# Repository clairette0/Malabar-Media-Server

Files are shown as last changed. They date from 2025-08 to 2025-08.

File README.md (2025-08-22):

# <div align="center">Malabar Media Server</div>

<div align="center">
  Malabar Media Server Offline Media Server
</div>

<p align="center"><b>A portable, offline media server powered by the ESP32-S3 in a thumbdrive form factor.</b><br>
Stream movies, music, books, and shows anywhere — no internet required.</p>

<p align="center">
  
  
  
</p>

---

##  Polish Update Disclaimer

This is a major update focused on **polish, stability, and usability improvements**.  
It includes:

- Full cleanup of reported bugs  
- Improved user interface  
- Rebuilt admin panel  
- New features across every section  
- All configuration options now available in the **frontend** — no need to modify firmware to change settings  
- Greatly enhanced file and media support  

---

## New Features in the Polish Update

###  Music Page

- Song downloads
- Loop songs 
- Sort songs A–Z
- Shuffle songs and playlists
- Playlist support via subfolders (flexible usage)
- Playlists loop automatically
- Expanded file type support: tested with `.mp3`, `.wav`, and `.flac` (others may work, untested)

###  Books Page

- EPUB support added (no web reader yet, but download works)
- Fixed footer CSS display issue

###  Admin Panel (Completely Rebuilt)

- Restart the device directly from the panel
- Switch to USB Mass Storage Mode with one click
- SD card usage tracking with visual indicators
- Control RGB LED color and mode
- Change or disable the admin password (for admin page access) (default is "password")
- Change Wi-Fi SSID and password
- Set device brightness (off option coming soon)
- Toggle `media.json` auto-generation on boot
- Generate `media.json` manually
- Display connected Wi-Fi info and number of connected users
- Integrated file system browser with jQueryFileTree:
  - Upload, delete, rename, download, create folder, and edit files (basic inline code editor)
  - Improved UX over the original browser, but still allows dangerous deletions, use with care.

###  Gallery Page (New)

- Displays images with basic zoom functionality
- Video playback support
- Sortable display grid

###  Files Page (New)

- Lets you store and download any file type
- Still limited to FAT32 file size limit (4 GB max)
- Useful for sharing non-media files like firmware, PDFs, etc.

###  Interface + UI Improvements

- LCD now displays “USB Mass Storage Mode” clearly — no more frozen screen confusion
- `media.json` generation displays file names in real-time on screen
- More intuitive screen feedback during long operations

###  File Type & Playback Support

- Improved video file detection and browser compatibility
- Works with almost all browser-supported video types
- Unsupported files fall back to download behavior

###  Admin Access Notes

- A new "Settings" button on the top-right of the menu screen leads to the Admin Panel
- Default admin password is `"password"`
- If locked out, inspect (F12) the overlay and delete it manually to regain access
- All settings now persist across reboots

---

## Experimental Branch Enhancements

This branch includes all current features being tested for stability before merging into `main`.

### Key Features

- Admin panel with controls for restart, USB mode, Wi-Fi, RGB, brightness, password, and media generation
- Frontend-based configuration (no firmware edits required)
- Full file system browser with upload, rename, delete, and inline editing
- Music player with playlist support, shuffle, loop, downloads, and file sorting
- Expanded audio format support (MP3, WAV, FLAC, and others)
- Books section with PDF support (and limited Epub support)
- Gallery page for browsing images and video playback
- Files page for general-purpose file sharing and downloads
- Media.json generation with live progress shown on screen
- LCD interface with USB mode status and SD card usage display
- Captive portal for easy user access
- OPDS support for eBook integration
- Basic DLNA support for media discovery on supported devices
- Custom UI built with SquareLine Studio
- Persistent settings stored across reboots
- Improved mobile-friendly web UI

Use this branch if you want the most up to date features, improved stability, and a much more polished experience. While still under active development, this is now the recommended version for most users and I will be pushing it to main after a few days of user testing. 

---

## What is Malabar Media Server

Malabar Media Server is an open-source offline media server built for travel, remote work, classrooms, camping, and more. It runs entirely on an ESP32-S3 dev board, creates a local Wi-Fi hotspot, and serves media through a browser-accessible interface. It does not require internet access and works similarly to in-flight entertainment systems. It also allows multiple users watching seperate media streams at the same time. 

This project is designed to be compact, simple, and easily modifiable. It includes optional 3D-printable hardware and a fully open source firmware and web interface.

---

## Project Inspiration
This project was inspired by my experience running a Jellyfin server at home. I love having full control over my media library, and Jellyfin gave me everything I wanted > streaming movies, shows, books, and music, all from my own hardware. Naturally, I started looking for ways to take that experience on the go.

My first thought was to build a portable server, but I quickly ran into some major hurdles:

- Power-hungry hardware — Even low-power x86 boxes needed a hefty battery setup to stay running for long trips.

- High cost — SBCs like the Raspberry Pi 4, plus power banks, USB storage, and screen interfaces added up quickly.

- Heat and reliability — Trying to cram a full stack of services into a compact case often led to thermal issues and instability when running software meant for server hardware.

That’s when I pivoted.

Instead of replicating a full home media server, I focused on delivering the core experience:

- Offline access

- Local Wi-Fi hotspot

- Simple media browsing and playback

- Support for multiple users

The ESP32-S3 offered just enough performance to handle all of that - with a fraction of the power draw and cost.
The result is Malabar Media Server: a minimalist, reliable, and low-cost media server that delivers the essential features of a home streaming setup in a smaller than pocket sized format.

Is it fancy? No.
Does it work? Absolutely.
And it’s open-source, so anyone can expand, improve, and adapt it for their own needs.

---

## Features

- Creates a local Wi-Fi hotspot with captive portal  
- Serves HTML media interface to any connected device  
- Streams content directly from a FAT32-formatted microSD card  
- Supports simultaneous connections (tested with up to 4 video streams)  
- No app or internet connection required  
- Open source firmware and UI  
- Customizable web interface / Features

---

## Hardware Requirements

**Disclaimer:**  
The following links are Amazon affiliate links. Purchasing through these links supports this project at no additional cost to you. Thank you for your support!

- **Waveshare ESP32-S3 Dev Board (1.47" LCD version)**  
  [https://amzn.to/4ktB6oT](https://amzn.to/4ktB6oT)

- **FAT32-formatted microSD card (16 GB minimum recommended, 64 GB preferred)**  
  [https://amzn.to/44tM1c4](https://amzn.to/44tM1c4)

- **SD-Card Extender** Not needed, but useful for the latest case version, lets you get to the SD card without disasembly. 
  [https://amzn.to/45IWIJz](https://amzn.to/45IWIJz)

- **USB power source** (e.g., battery bank or computer)

- **Optional:** 3D-printed enclosure (STL files included in the repository)

---

## Software Requirements

- Arduino IDE or PlatformIO (to flash firmware)
- Python 3.x (to run `media.py`)
- SquareLine Studio (optional, for screen UI editing)

All software used is free and available on Windows, macOS, and Linux.

---

## Quick Start

1. Flash the ESP32-S3 with the firmware in the `/firmware/` directory.
2. Format your SD card as **FAT32** and copy the web files from `/SD_Card_Template/`.
3. Place your media files into the appropriate folders (see structure below).
4. Run `media.py` to generate `media.json` automatically.
5. Insert the SD card and power the device.
6. Connect to the Wi-Fi network named `Malabar_Media_Server`.
7. Your browser will be redirected to the offline media interface.

---

## Folder Structure (on SD Card)

```
/Movies/
    Interstellar.mp4
    Interstellar.jpg
/Shows/
    The Office/
        S01E01 - Pilot.mp4
        S01E02 - Diversity Day.mp4
    The Office.jpg
/Books/
    The Martian.pdf
    The Martian.jpg
/Music/
    track01.mp3

index.html
appleindex.html
menu.html
movies.html
shows.html
books.html
music.html
media.py
media.json
placeholder.jpg
Logo.png
favicon.ico
```
---

## Supported Formats

- Video: `.mp4`
- Audio: `.mp3`
- Books: `.pdf`
- Images: `.jpg` (used for covers and folder images only)

Ensure all images and media files use matching names for proper display.

---

## Customization

- Wi-Fi name and password can be changed in `firmware/MalabarMediaServerProject/MalabarMediaServerProject.ino`
- Branding (logo, favicon) can be replaced in `/SD_Card_Template/`
- Sections (Movies, Music, etc.) can be removed from `menu.html`
- Web interface can be edited using any text editor
- The screen UI can be edited with SquareLine Studio (the free version is fine) 

---

## What's Included

- `/firmware/` – Arduino firmware for ESP32-S3
- `/SD_Card_Template/` – Web UI, HTML files, and `media.py`
- `/case/` – STL files for optional 3D-printed enclosure
- `/docs/` – Logos, screenshots, and design files

---

## Troubleshooting

Common issues and their solutions are detailed in the Troubleshooting section on instructibles.

Topics covered include:

- SD card read errors
- Captive portal issues on some phones
- Video playback and seeking bugs
- UI glitches or screen failure

---

## Future Plans

These are features I'd like to explore in future updates. If you'd like to contribute, feel free to fork the repo or open a pull request!

### Offline Maps with GPS Support
Inspired by [Backcountry Beacon](https://www.instructables.com/USB-Powered-Offline-Map-Server/), the goal is to serve cached map tiles and display the live GPS position from the user's phone or connected device — entirely offline.

### HTML5 Games
Similar to [Gams Offline](https://github.com/Gams-Offline/Gams), I would like to embed simple HTML5 games that work in-browser. The selection in Gams is amazing and make me think of cool math games, would be neat to have even though most require a keyboard.

### Audiobook-Friendly Mode
Improve playback for long-form audio by adding bookmarks, chapter display, and smart pause/resume. Intended for better audiobook handling in the Music section. Potentialy add an entire new audiobook section or a seperate handling system for it in books (Under read it could have a listen option).

---

## Build Guide on Instructables

Looking for a step-by-step tutorial?  
Check out the full build guide on **Instructables** for detailed instructions, photos, and tips on setting up Malabar Media Server.

👉 [Read the Instructables Guide](https://www.instructables.com/Jcorp-Nomad-Mini-WIFI-Media-Server/) 

---

## License

This project is licensed under the [Creative Commons Attribution-NonCommercial-ShareAlike 4.0 International License](https://creativecommons.org/licenses/by-nc-sa/4.0/).

You may remix, adapt, and share this project **for non-commercial use**, as long as you give credit and share under the same terms.

For commercial licensing, please contact the author.

---

## Credits

Developed by **Jackson Studner (Jcorp Tech)**.  
Inspired by open-source offline projects like Backcountry Beacon.

If you build, remix, or improve this project, please consider submitting a pull request or tagging the project.

---

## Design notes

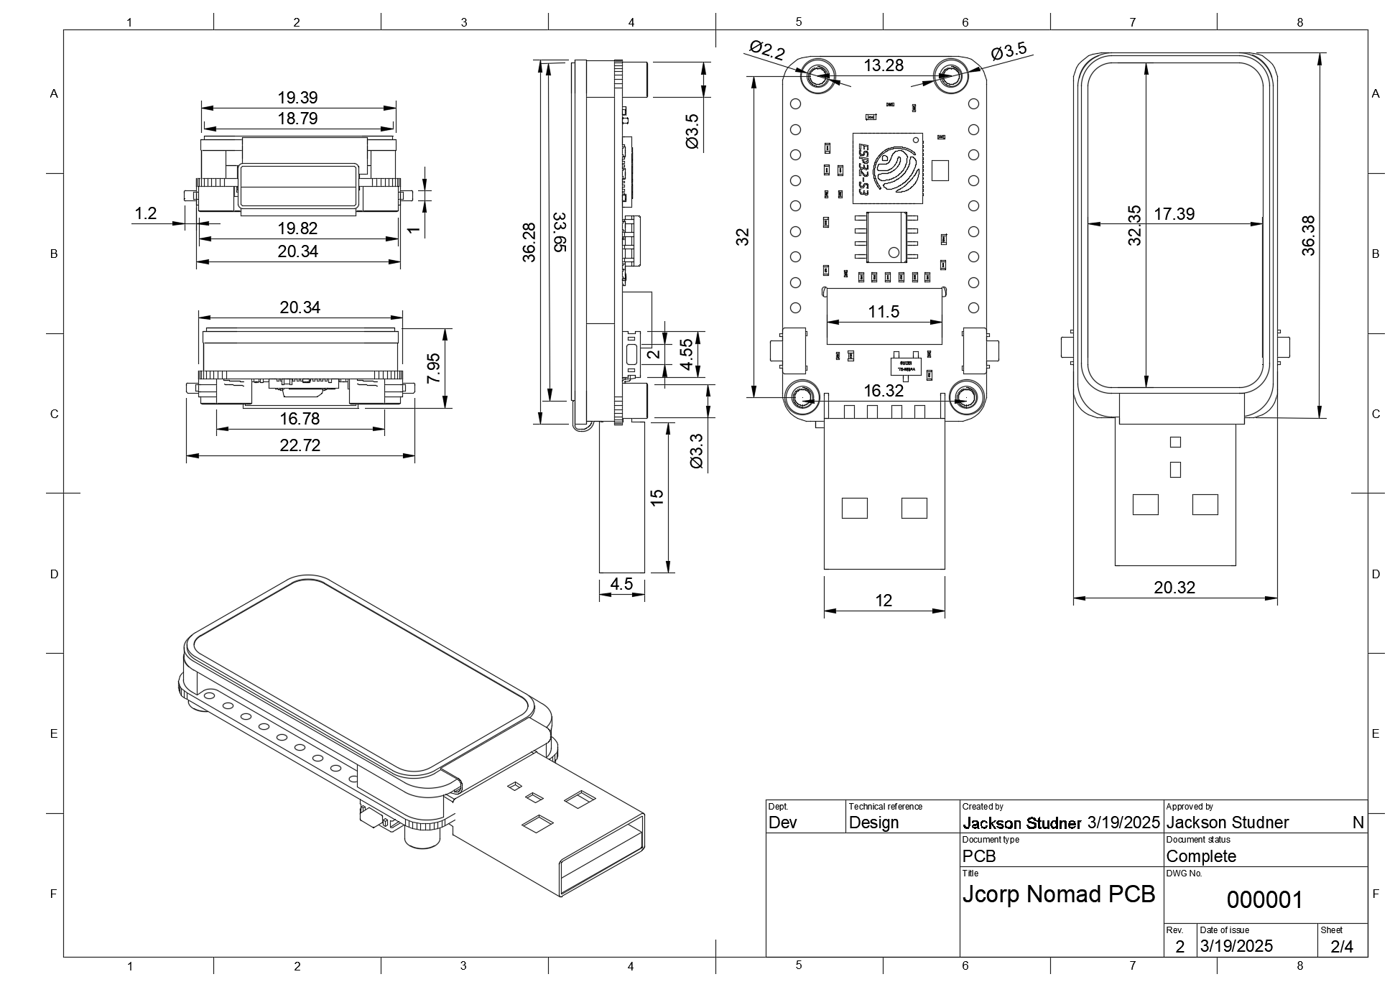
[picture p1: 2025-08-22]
docs/Malabar Technical Diagram.png

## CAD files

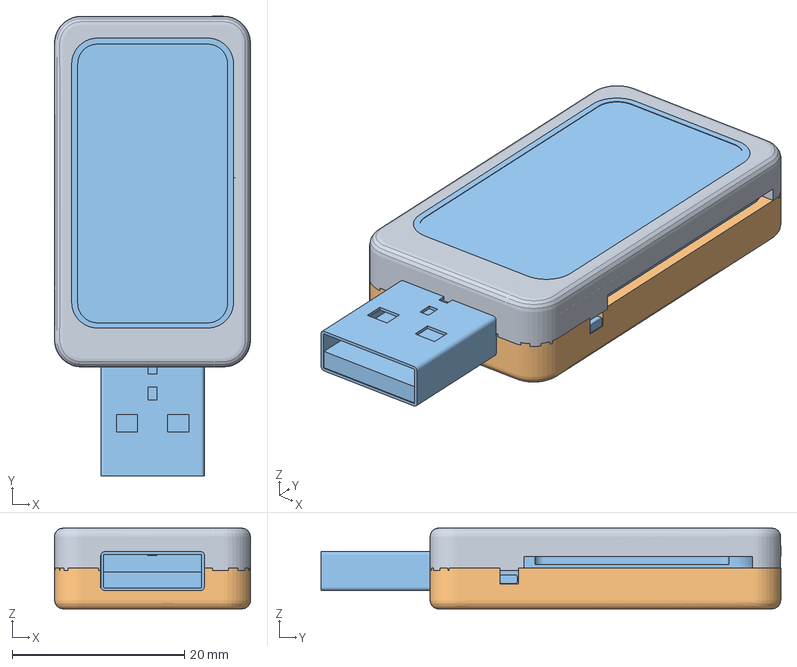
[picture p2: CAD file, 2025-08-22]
docs/MalabarFullTest.3mf
22.7 x 53.3 x 9.39 mm

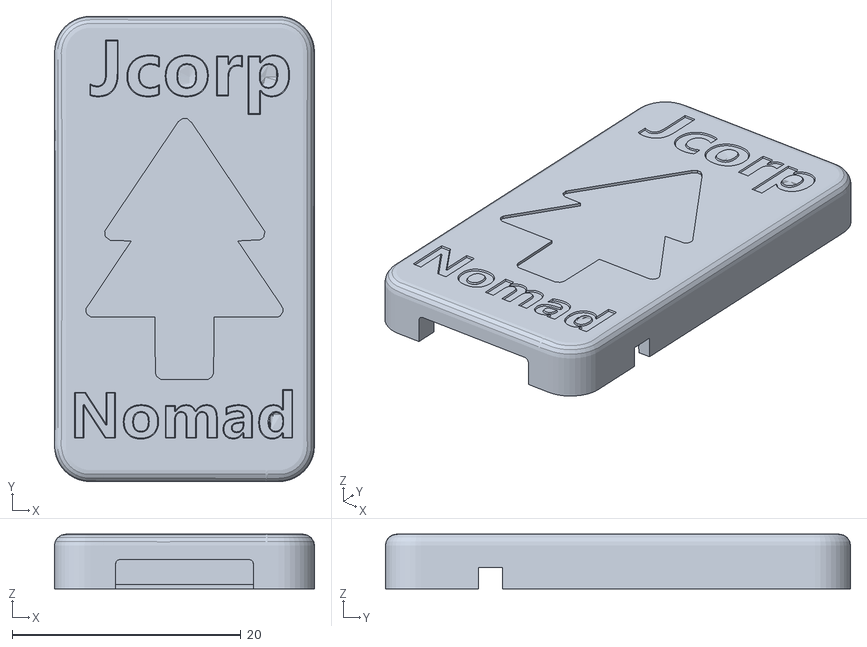
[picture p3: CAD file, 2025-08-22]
case/MalabarMediaServerBackCover.stl
22.7 x 40.7 x 4.78

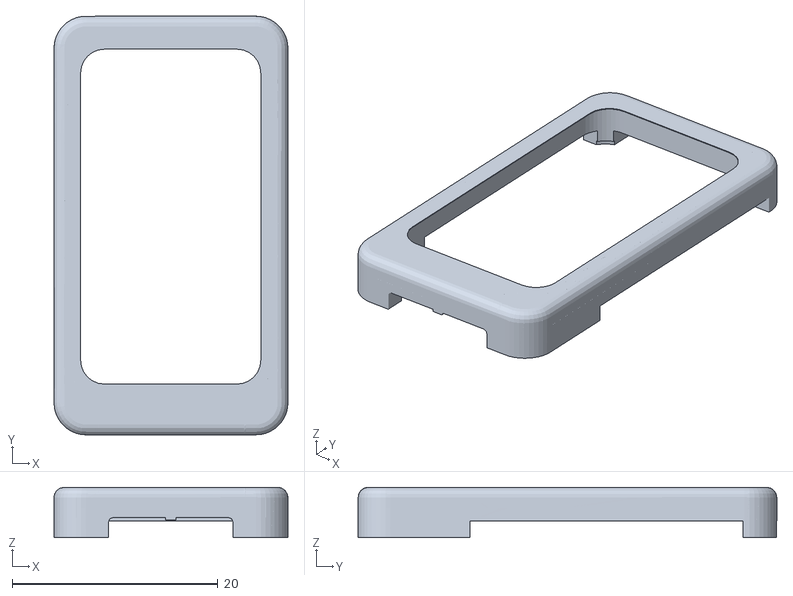
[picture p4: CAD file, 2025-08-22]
case/MalabarMediaServerFrontCover.stl
22.7 x 40.7 x 4.90

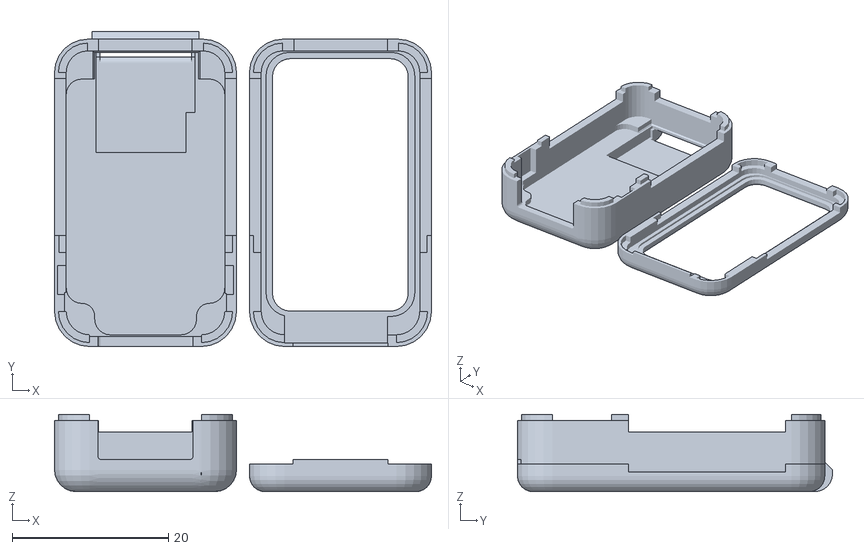
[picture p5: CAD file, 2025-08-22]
case/MalabarNewCase v16.stl
48.3 x 40.4 x 9.92

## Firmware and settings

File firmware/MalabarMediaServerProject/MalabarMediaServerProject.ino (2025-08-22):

//Malabar Media Server Project
#include "Arduino.h"
#define FF_USE_FASTSEEK 1
#define SD_FREQ_KHZ 10000         // ✱✱ VERY IMPORTANT SETTING ✱✱
                                  // This controls how fast reads from your SD Card can go, If you have a name brand fancy card you can go faster with better results. Check what your card recomends. 
                                  // 10 000 kHz (10 MHz) = safest 
                                  // 12000 kHz (12 MHz) = good 
                                  // 20000 kHz (20 MHz) = fastest 
#include "WiFi.h"
#include "ESPAsyncWebServer.h"
#include "FS.h"
#include "SD_MMC.h"
#include "DNSServer.h"
#include <ArduinoJson.h>
#include <map>
#include "Display_ST7789.h"
#include "LVGL_Driver.h"
#include "ui.h"
#include "RGB_lamp.h"
#include <SPIFFS.h>
#include <Preferences.h>
#include "esp_wifi.h"
#include "usb_mode.h"
#include "boot_mode.h" // custom library for firmware switching
void launch_usb_mode() {
extern void usb_setup();
extern void usb_loop();
  // Initialize only the USB‑MSC path
  usb_setup();

  // Then run only that path forever
  for (;;) {
    usb_loop();
    // optionally: delay(0); yield();
  }
}
#define BOOT_BUTTON_PIN 0  
int screenBrightness = 100; // 0-100, default full brightness
void handleConnector(AsyncWebServerRequest *request);
unsigned long lastTempReading = 0;
float currentTempC = 0.0;
static bool sdScanned = false;
const uint32_t SD_SCAN_DELAY = 5000;  // milliseconds after boot
// ==================== CONFIGURATION ====================

// Max number of devices that can connect at once
#define MAX_CLIENTS 4 // I recomend 4, If you want to try more knock yourself out!

struct AdminSettings {
  String rgbMode = "off";
  String rgbColor = "#ff0000";
  String adminPassword = "";
  String wifiSSID = "Malabar_Media_Server";
  String wifiPassword = "password";
  int brightness = 230;
  bool autoGenerateMedia = false;
};

AdminSettings settings;
const char* SETTINGS_PATH = "/config/settings.json";
// =================== scary config ====================
// SD card pinout for Waveshare ESP32-S3
#define SD_CLK_PIN 14
#define SD_CMD_PIN 15
#define SD_D0_PIN 16
#define SD_D1_PIN 18
#define SD_D2_PIN 17
#define SD_D3_PIN 21
// ---------------URL Encode -------------
String urlencode(String str) {
  String encoded = "";
  char c;
  char code0, code1;
  char code[] = "0123456789ABCDEF";

  for (int i = 0; i < str.length(); i++) {
    c = str.charAt(i);
    if (isalnum(c)) {
      encoded += c;
    } else {
      code0 = code[(c >> 4) & 0xF];
      code1 = code[c & 0xF];
      encoded += '%';
      encoded += code0;
      encoded += code1;
    }
  }
  return encoded;
}
// Settings Setup:
bool loadSettings() {
  if (!SD_MMC.exists(SETTINGS_PATH)) {
    Serial.println("Settings file not found. Generating default.");
    return saveSettings();  // Save defaults
  }

  File file = SD_MMC.open(SETTINGS_PATH);
  if (!file || file.isDirectory()) {
    Serial.println("Failed to open settings file.");
    return false;
  }

  StaticJsonDocument<512> doc;
  DeserializationError error = deserializeJson(doc, file);
  file.close();

  if (error) {
    Serial.println("Failed to parse settings JSON.");
    return false;
  }

  settings.rgbMode = doc["rgbMode"] | "off";
  settings.rgbColor = doc["rgbColor"] | "#ff0000";
  settings.adminPassword = doc["adminPassword"] | "";
  settings.wifiSSID = doc["wifiSSID"] | "Malabar_Media_Server";
  settings.wifiPassword = doc["wifiPassword"] | "password";
  settings.brightness = doc["brightness"] | 230;
  settings.autoGenerateMedia = doc["autoGenerateMedia"] | false;

  return true;
}
bool saveSettings() {
  SD_MMC.mkdir("/config"); // Ensure directory exists

  File file = SD_MMC.open(SETTINGS_PATH, FILE_WRITE);
  if (!file) {
    Serial.println("Failed to open settings file for writing.");
    return false;
  }

  StaticJsonDocument<512> doc;
  doc["rgbMode"] = settings.rgbMode;
  doc["rgbColor"] = settings.rgbColor;
  doc["adminPassword"] = settings.adminPassword;
  doc["wifiSSID"] = settings.wifiSSID;
  doc["wifiPassword"] = settings.wifiPassword;
  doc["brightness"] = settings.brightness;
  doc["autoGenerateMedia"] = settings.autoGenerateMedia;

  bool success = serializeJson(doc, file) > 0;
  file.close();
  return success;
}

// --------------- Media Generation Stuff ------------
bool isAlwaysGenerateEnabled() {
    return SD_MMC.exists("/always_generate.flag");
}

void enableAlwaysGenerate() {
    File f = SD_MMC.open("/always_generate.flag", FILE_WRITE);
    if (f) {
        f.print("1");
        f.close();
    }
}

void disableAlwaysGenerate() {
    SD_MMC.remove("/always_generate.flag");
}

bool isOneTimeGenerateRequested() {
    return SD_MMC.exists("/generate_once.flag");
}

void requestOneTimeGenerate() {
    File f = SD_MMC.open("/generate_once.flag", FILE_WRITE);
    if (f) {
        f.print("1");
        f.close();
    }
}

void clearOneTimeGenerate() {
    SD_MMC.remove("/generate_once.flag");
}
//------------------- delete recursive for admin -------------
bool deleteRecursive(String path) {
  File entry = SD_MMC.open(path);
  if (!entry) return false;

  if (!entry.isDirectory()) {
    entry.close();
    return SD_MMC.remove(path);
  }

  File child;
  while ((child = entry.openNextFile())) {
    String childPath = String(path) + "/" + child.name();
    deleteRecursive(childPath);
    child.close();
  }

  entry.close();
  return SD_MMC.rmdir(path);
}


// ───────────────── SD‑recovery globals ───────────────
volatile bool sdErrorFlag            = false;      
unsigned long sdErrorCooldownUntil   = 0;          

bool tryRecoverSDCard() {                          
    Serial.println("[SD] Attempting recovery…");
    SD_MMC.end();          // unmount
    delay(1000);           // give hardware a breather

    if (!SD_MMC.begin("/sdcard", true, false, SD_FREQ_KHZ, 12)) {
        Serial.println("[SD] Recovery failed.");
        return false;
    }
    Serial.println("[SD] Recovery OK.");
    return true;
}

String rfc3339Now() {
  return "2025-07-12T12:00:00Z";  // Hard-coded UTC timestamp, or it gets mad
}

// Captive portal DNS setup
const byte DNS_PORT = 53;
DNSServer dnsServer;
AsyncWebServer server(80); // Web server on port 80
std::map<AsyncWebServerRequest*, File> activeUploads;
int connectedClients = 0;
// LED Mode and Color Helper Wrappers
uint8_t currentLEDMode = 0;  // 0=off, 1=rainbow, 2=solid color
uint8_t solidR = 0, solidG = 0, solidB = 0;
void RGB_SetColor(uint8_t r, uint8_t g, uint8_t b) {
    solidR = r;
    solidG = g;
    solidB = b;
    currentLEDMode = 2; 
    Set_Color(g, r, b);
}
extern lv_obj_t *ui_wifi;
extern lv_obj_t *ui_SDcard;
bool lastWifiStatus = false;
bool lastSDStatus = false;
//Globals for SD scan
unsigned long lastUpdateTime = 0;
unsigned long lastSDScanTime = 0;
const unsigned long SD_SCAN_INTERVAL = 60000; // 60 seconds
uint64_t cachedUsedBytes = 0;
uint64_t cachedTotalBytes = 0;
unsigned long lastScanTime = 0;
// Update the UI with the number of connected users
void updateUI(int userCount) {
    char buffer[10];
    snprintf(buffer, sizeof(buffer), "%d", userCount);
    lv_label_set_text(ui_userlabel, buffer);
}
void updateToggleStatus() {
    bool currentWifiStatus = WiFi.softAPIP();
    if (currentWifiStatus != lastWifiStatus) {
        if (currentWifiStatus) {
            lv_obj_add_state(ui_wifi, LV_STATE_CHECKED);
        } else {
            lv_obj_clear_state(ui_wifi, LV_STATE_CHECKED);
            Serial.println("[Status] WiFi AP failure detected.");
        }
        lastWifiStatus = currentWifiStatus;
    }

bool currentSDStatus = SD_MMC.cardType() != CARD_NONE;   // ✱✱ NEW / CHANGED ✱✱
    if (currentSDStatus != lastSDStatus) {
        if (currentSDStatus) {
            lv_obj_add_state(ui_SDcard, LV_STATE_CHECKED);
        } else {
            lv_obj_clear_state(ui_SDcard, LV_STATE_CHECKED);
            Serial.println("[Status] SD card failure detected.");
        }
        lastSDStatus = currentSDStatus;
    }
}

// Stream a chunk of text to save RAM
void opdsWrite(AsyncResponseStream *s, const String &chunk) {
    s->print(chunk);
}
//(OPDS thing)
String xmlEscape(const String &in) {        // we already added this
  String out;
  for (char c : in) {
    switch (c) {
      case '&':  out += "&amp;";  break;
      case '<':  out += "&lt;";   break;
      case '>':  out += "&gt;";   break;
      default:   out += c;        break;
    }
  }
  return out;
}

String slugify(const String &in) {          // new helper
  String out;
  for (char c : in) {
    if (isalnum(c))       out += (char)tolower(c);
    else if (c==' ' || c=='_' || c=='-') out += '-';
    // every other char is dropped
  }
  return out;
}

// Get a count of currently connected WiFi clients
void updateClientCount() {
    wifi_sta_list_t wifi_sta_list;
    if (esp_wifi_ap_get_sta_list(&wifi_sta_list) == ESP_OK) {
        connectedClients = wifi_sta_list.num;
        updateUI(connectedClients);
    }
}

// Utility: extract base name (no path, no extension)
String getFileBaseName(const String& name) {
    String base = name.substring(name.lastIndexOf('/') + 1);
    int dotIndex = base.lastIndexOf('.');
    if (dotIndex != -1) base = base.substring(0, dotIndex);
    return base;
}
bool isValidExtension(const String& filename, const std::vector<String>& exts) {
  String nameLower = filename;
  nameLower.toLowerCase();
  for (const auto& ext : exts) {
    if (nameLower.endsWith(ext)) return true;
  }
  return false;
}

void generateMediaJSON() {
    // ─── 1) Open the JSON file ───
    File jsonFile = SD_MMC.open("/media.json", FILE_WRITE);
    if (!jsonFile) {
        Serial.println("[MediaGen] ERROR: cannot open media.json for writing");
        return;
    }

    // ─── 2) Write opening brace ───
    jsonFile.println("{");

    // ─── 3) Initialize LVGL status screen ───
    lv_obj_clear_flag(ui_MediaGen, LV_OBJ_FLAG_HIDDEN);
    String logBuf = "Generating media.json...\n";
    int logCount = 0;
    const int LOG_UPDATE_INTERVAL = 20;
    lv_textarea_set_text(ui_MediaGen, logBuf.c_str());
    lv_timer_handler();

    // Helper lambda to flush log
    auto flushLog = [&]() {
        lv_textarea_set_text(ui_MediaGen, logBuf.c_str());
        lv_textarea_set_cursor_pos(ui_MediaGen, logBuf.length());
        lv_timer_handler();
        logBuf = "";
        logCount = 0;
    };

    // ─── 4) Movies ───
    jsonFile.println("  \"movies\": [");
    File moviesDir = SD_MMC.open("/Movies");
    bool firstMovie = true;
    std::vector<String> movieExts = {".mp4", ".mkv", ".avi", ".mov", ".webm", ".m4v", ".wmv", ".flv", ".mpg", ".mpeg", ".ts", ".3gp"};
    while (File file = moviesDir.openNextFile()) {
        yield();
        String fname = String(file.name());
        String ext = fname.substring(fname.lastIndexOf('.'));
        ext.toLowerCase();
        if (!file.isDirectory() && isValidExtension(fname, movieExts)) {
            if (!firstMovie) jsonFile.println(",");
            firstMovie = false;
            String base = getFileBaseName(fname);
            String cover = SD_MMC.exists("/Movies/" + base + ".jpg") ? "movies/" + base + ".jpg" : "placeholder.jpg";

            jsonFile.print("    { \"name\": \"" + base + "\", \"cover\": \"" + cover + "\", \"file\": \"Movies/" + base + ext + "\" }");

            logBuf += "- " + fname + "\n";
            if (++logCount % LOG_UPDATE_INTERVAL == 0) flushLog();
        }
    }
    jsonFile.println();
    jsonFile.println("  ],");
    flushLog();

    // ─── 5) Shows ───
    jsonFile.println("  \"shows\": [");
    File showsRoot = SD_MMC.open("/Shows");
    bool firstShow = true;
    while (File folder = showsRoot.openNextFile()) {
        yield();
        if (folder.isDirectory()) {
            if (!firstShow) jsonFile.println(",");
            firstShow = false;
            String showName = String(folder.name());
            String cover = SD_MMC.exists("/Shows/" + showName + ".jpg") ? "shows/" + showName + ".jpg" : "placeholder.jpg";

            jsonFile.println("    {\"name\": \"" + showName + "\", \"cover\": \"" + cover + "\", \"episodes\": [");

            logBuf += "Show: " + showName + "\n";
            if (++logCount % LOG_UPDATE_INTERVAL == 0) flushLog();

            File epDir = SD_MMC.open("/Shows/" + showName);
            bool firstEp = true;
            while (File ep = epDir.openNextFile()) {
                yield();
                String epName = String(ep.name());
                String epExt = epName.substring(epName.lastIndexOf('.'));
                epExt.toLowerCase();
                if (!ep.isDirectory() && isValidExtension(epName, movieExts)) {
                    if (!firstEp) jsonFile.println(",");
                    firstEp = false;
                    String epBase = getFileBaseName(epName);
                    jsonFile.print("      { \"name\": \"" + epBase + "\", \"file\": \"Shows/" + showName + "/" + epBase + epExt + "\" }");

                    logBuf += "  * " + epName + "\n";
                    if (++logCount % LOG_UPDATE_INTERVAL == 0) flushLog();
                }
            }
            jsonFile.println();
            jsonFile.println("    ]}");
        }
    }
    jsonFile.println();
    jsonFile.println("  ],");
    flushLog();

    // ─── 6) Books ───
    jsonFile.println("  \"books\": [");
    File booksDir = SD_MMC.open("/Books");
    bool firstBook = true;
    std::vector<String> bookExts = {".pdf", ".epub", ".mobi", ".azw3", ".txt"};
    while (File file = booksDir.openNextFile()) {
        yield();
        String fname = String(file.name());
        String ext = fname.substring(fname.lastIndexOf('.'));
        if (!file.isDirectory() && isValidExtension(fname, bookExts)) {
            if (!firstBook) jsonFile.println(",");
            firstBook = false;
            String base = getFileBaseName(fname);
            String cover = SD_MMC.exists("/Books/" + base + ".jpg") ? "books/" + base + ".jpg" : "placeholder.jpg";

            jsonFile.print("    { \"name\": \"" + base + "\", \"cover\": \"" + cover + "\", \"file\": \"Books/" + base + ext + "\" }");

            logBuf += "- " + fname + "\n";
            if (++logCount % LOG_UPDATE_INTERVAL == 0) flushLog();
        }
    }
    jsonFile.println();
    jsonFile.println("  ],");
    flushLog();

    // ─── 7) Music ───
    jsonFile.println("  \"music\": [");
    File musicDir = SD_MMC.open("/Music");
    bool firstMusic = true;
    std::vector<String> musicExts = {".mp3", ".wav", ".flac"};
    while (File file = musicDir.openNextFile()) {
        yield();
        String fname = String(file.name());
        String ext = fname.substring(fname.lastIndexOf('.'));
        ext.toLowerCase();
        if (!file.isDirectory() && isValidExtension(fname, musicExts)) {
            if (!firstMusic) jsonFile.println(",");
            firstMusic = false;
            String base = getFileBaseName(fname);
            String cover = SD_MMC.exists("/Music/" + base + ".jpg") ? "music/" + base + ".jpg" : "placeholder.jpg";

            jsonFile.print("    { \"name\": \"" + base + "\", \"cover\": \"" + cover + "\", \"file\": \"Music/" + base + ext + "\" }");

            logBuf += "- " + fname + "\n";
            if (++logCount % LOG_UPDATE_INTERVAL == 0) flushLog();
        }
    }
    jsonFile.println();
    jsonFile.println("  ],");
    flushLog();

    // ─── 8) Playlists ───
    jsonFile.println("  \"playlists\": {");
    File musicRoot = SD_MMC.open("/Music");
    bool firstPl = true;
    while (File folder = musicRoot.openNextFile()) {
        yield();
        if (folder.isDirectory()) {
            if (!firstPl) jsonFile.println(",");
            firstPl = false;
            String plName = String(folder.name());
            jsonFile.println("    \"" + plName + "\": [");

            logBuf += "Playlist: " + plName + "\n";
            if (++logCount % LOG_UPDATE_INTERVAL == 0) flushLog();

            std::vector<String> tracks;
            std::function<void(File,const String&)> collectTracks =
                [&](File dir, const String& rel) {
                    while (File t = dir.openNextFile()) {
                        yield();
                        String name = rel + "/" + String(t.name());
                        if (t.isDirectory()) collectTracks(SD_MMC.open("/Music/" + name), name);
                        else if (isValidExtension(name, musicExts)) tracks.push_back(name);
                    }
                };
            collectTracks(SD_MMC.open("/Music/" + plName), plName);

            for (size_t i = 0; i < tracks.size(); ++i) {
                String tname = tracks[i].substring(tracks[i].lastIndexOf('/') + 1);
                String base2 = getFileBaseName(tname);
                String cover2 = SD_MMC.exists("/Music/" + base2 + ".jpg") ? "music/" + base2 + ".jpg" : "placeholder.jpg";
                jsonFile.print("      { \"name\": \"" + base2 + "\", \"cover\": \"" + cover2 + "\", \"file\": \"Music/" + tracks[i] + "\" }");
                if (i < tracks.size() - 1) jsonFile.println(",");

                logBuf += "  * " + tname + "\n";
                if (++logCount % LOG_UPDATE_INTERVAL == 0) flushLog();
            }
            jsonFile.println();
            jsonFile.println("    ]");
        }
    }
    jsonFile.println("  },");
    flushLog();

    // ─── 9) Gallery ───
    jsonFile.println("  \"gallery\": [");
    File galleryDir = SD_MMC.open("/Gallery");
    bool firstGal = true;
    std::vector<String> mediaExts = {".jpg", ".jpeg", ".png", ".bmp", ".gif", ".webp", ".tiff", ".mp4", ".webm", ".mov", ".avi", ".mkv", ".flv"};
    while (File f = galleryDir.openNextFile()) {
        yield();
        String fname = String(f.name());
        String ext2 = fname.substring(fname.lastIndexOf('.')); ext2.toLowerCase();
        if (!f.isDirectory() && isValidExtension(fname, mediaExts)) {
            if (!firstGal) jsonFile.println(",");
            firstGal = false;
            String base = getFileBaseName(fname);
            jsonFile.print("    { \"name\": \"" + base + "\", \"file\": \"Gallery/" + fname + "\" }");

            logBuf += "- " + fname + "\n";
            if (++logCount % LOG_UPDATE_INTERVAL == 0) flushLog();
        }
    }
    jsonFile.println();
    jsonFile.println("  ],");
    flushLog();

    // ─── 10) Files ───
    jsonFile.println("  \"files\": [");
    File filesDir = SD_MMC.open("/Files");
    bool firstFile = true;
    while (File f = filesDir.openNextFile()) {
        yield();
        String fname = String(f.name());
        if (!f.isDirectory()) {
            if (!firstFile) jsonFile.println(",");
            firstFile = false;
            jsonFile.print("    { \"name\": \"" + fname + "\", \"file\": \"Files/" + fname + "\" }");

            logBuf += "- " + fname + "\n";
            if (++logCount % LOG_UPDATE_INTERVAL == 0) flushLog();
        }
    }
    jsonFile.println();
    jsonFile.println("  ]");
    flushLog();

    // ─── 11) Close JSON and finish ───
    jsonFile.println("}");
    jsonFile.close();

    Serial.println("[MediaGen] media.json created successfully.");
    lv_obj_add_flag(ui_MediaGen, LV_OBJ_FLAG_HIDDEN);
}

String absURL(const String &path) {
    return "http://" + WiFi.softAPIP().toString() + path;
}


void handleOPDSRoot(AsyncWebServerRequest *request) {
    AsyncResponseStream *res = request->beginResponseStream(
        "application/atom+xml;profile=opds-catalog;kind=navigation");

    opdsWrite(res, "<?xml version=\"1.0\" encoding=\"utf-8\"?>\n"
                   "<feed xmlns=\"http://www.w3.org/2005/Atom\" "
                   "xmlns:opds=\"http://opds-spec.org/2010/catalog\">\n");

    opdsWrite(res, "  <id>urn:uuid:malabar-opds-root</id>\n"
                   "  <title>Malabar OPDS Catalog</title>\n"
                   "  <updated>2025-07-12T12:00:00Z</updated>\n"
                   "  <author><name>Malabar Server</name></author>\n");

    // Add required navigation links
    opdsWrite(res, "  <link rel=\"self\" href=\"" + absURL("/opds/root.xml") + "\" "
                   "type=\"application/atom+xml;profile=opds-catalog;kind=navigation\"/>\n");
    opdsWrite(res, "  <link rel=\"start\" href=\"" + absURL("/opds/root.xml") + "\" "
                   "type=\"application/atom+xml;profile=opds-catalog;kind=navigation\"/>\n");

    opdsWrite(res, "  <entry>\n"
                   "    <title>All Books</title>\n"
                   "    <id>urn:uuid:malabar-opds-books</id>\n"
                   "    <updated>2025-07-12T12:00:00Z</updated>\n"
                   "    <link rel=\"http://opds-spec.org/catalog\" "
                   "type=\"application/atom+xml;profile=opds-catalog;kind=acquisition\" "
                   "href=\"" + absURL("/opds/books.xml") + "\"/>\n"
                   "  </entry>\n");

    opdsWrite(res, "</feed>");
    request->send(res);
}
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
void loop() {
    dnsServer.processNextRequest();
    Timer_Loop();

    if (currentLEDMode == 1) {
        RGB_Lamp_Loop(2);
    }
    if (sdErrorFlag) {                                            
        if (millis() > sdErrorCooldownUntil && tryRecoverSDCard()) {
            sdErrorFlag = false;  // we’re back in business
        } else {
            delay(5);  // keep feeding WDT while waiting
            return;    // skip rest of loop until recovery works
        }
    }
    // Update UI toggle status every second
    if (millis() - lastUpdateTime > 1000) {
        updateToggleStatus();
        lastUpdateTime = millis();
    }

    if (millis() - lastTempReading > 6000) {
      currentTempC = temperatureRead();
      lastTempReading = millis();
    }
  
    delay(5); // Prevent watchdog starvation
    updateClientCount();
}


void RGB_SetMode(uint8_t mode) {
    currentLEDMode = mode;

    if (mode == 0) {
        // Turn off LED immediately
        Set_Color(0, 0, 0);
    } else if (mode == 2) {
        Set_Color(solidG, solidR, solidB);
    }
}

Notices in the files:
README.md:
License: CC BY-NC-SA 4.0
